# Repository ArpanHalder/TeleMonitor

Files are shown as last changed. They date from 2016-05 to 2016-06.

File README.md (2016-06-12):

# TeleMonitor
This Open Hardware initiative is focused mostly on industrial application. In fact, this started with designing a low-cost Telemonitoring system for Mining Industry Applications. It is an embedded data transmission setup made up on small Arduino like boards. For long distance communication between device nodes, it uses RS-485

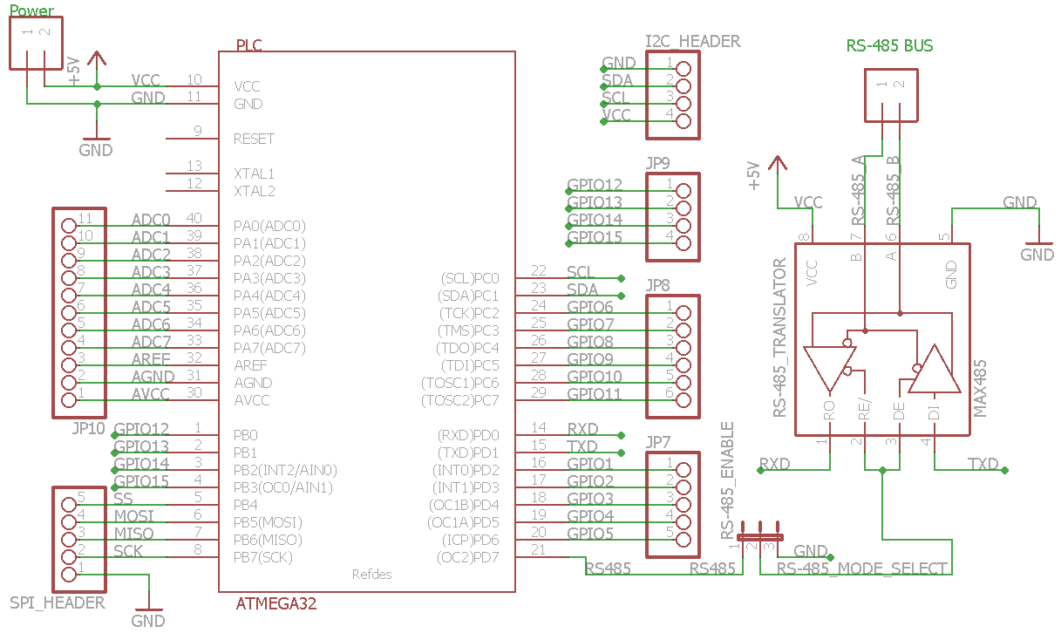
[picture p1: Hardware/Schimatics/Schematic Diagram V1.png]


##Motivation
While working in the laboratory, our team did experiment similar thing using state of the art services. However, not every educational institute has access to premium facilities. This project is initiated to enable us (who have access to premium education) to build some full-scale copyleft open technology that can be used for demonstration of remote monitoring operation in academia as well as in industries.
(After the device, hopefully soon the projects for IDE of this instrument, and Open Source Analytics & Visualization tools for this project shall be published after development of first working prototype.)

##Design Approaches
One of the primary objectives is keeping the hardware cheap, straightforward and reparable. We don't want a design where if one component fails the whole circuit is replaced, which create extra junk on the surface of the earth.

###This Device is motivated by the idea of "Democratisation of Technology & Education."
<https://en.wikipedia.org/wiki/Democratization_of_technology>

<http://www.thehindu.com/news/national/andhra-pradesh/science-should-touch-lives-of-common-people/article8539013.ece>

This is why we wish to keep the design simple and affordable like DIY projects, however, rich with all necessary features. This we can hopefully achieve by the cognitive support of the community. We also suggest restricting use of components in the design that tier III nations cannot afford to import or implement in the industries. 

##Ways to Contribute in this project

Discuss the possible improvement, and feature requirements.

Contact : tech.halder.arpan@gmail.com

[master_diag]: https://github.com/ArpanHalder/TeleMonitor/blob/master/Hardware/Schimatics/Schematic%20Diagram%20V1.png

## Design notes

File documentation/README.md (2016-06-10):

#Images depict

Network Layers in BUS implimentation of telemonitor board :"TeleMonitorProtocol.PNG"

Abstract concept of TeleMonitor Device : "Abstract Concept .png"

Pin mapping in TeleMonitor: "ATmega 40 Pin layout.PNG"

//TODO : Update explaind revison of bare  minimum code skeliton.

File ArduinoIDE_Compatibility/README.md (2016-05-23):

#How to add TeleMonitor Universal IoT Platform on Arduino1.0.x device list.

copy and add contents of boards.txt to existing boards.txt which is in your \<arduino IDE directory\> / hardware/boards.txt

Next copy the folder TeleMonitorATmega16-32 in your \<arduino IDE directory\>/hardware/variants/

then restart the IDE. (in case you're using STINO with sublime-text you only need to refresh.) 

**Please Note:** Here the compatibility files shall only help to program the MCU used in TeleMonitor Device with Arduino as ISP mode.

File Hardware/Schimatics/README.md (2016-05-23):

#Hardware Schematics for Telemonitoring nodes



## How to Read/Open

The files are made with eagle cad. 

There are image files naming  *.PNG  

Currently Schematics is drawn in a way which can easily be implimented with one sided perforated board. (to avoid PCB printing cost for early developers.) 

**Please Note:** the top layer on PCB (the red streaks) need not to be solder bridged, rather a thin wire may be used which shall be soldered on bottom side.

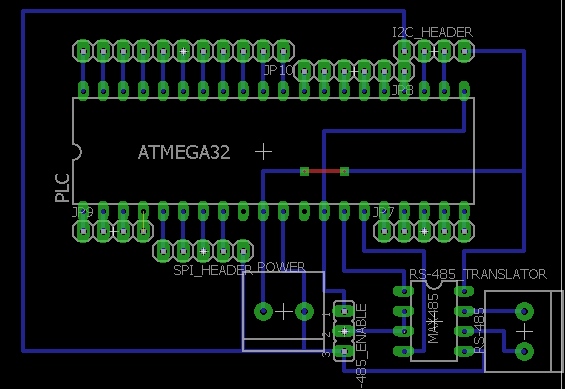
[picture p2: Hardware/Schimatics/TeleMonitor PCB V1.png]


### Current Job
~~Looking forward to make a vias less PCB that can be printed and fabricated manually.~~

~~On Veroboard~~

Add more necessary components and rearrangement for improvements. 

[master_diag]: https://github.com/ArpanHalder/TeleMonitor/blob/master/Hardware/Schimatics/Schematic%20Diagram%20V1.png

[master_pcb]: https://github.com/ArpanHalder/TeleMonitor/blob/master/Hardware/Schimatics/TeleMonitor%20PCB%20V1.png

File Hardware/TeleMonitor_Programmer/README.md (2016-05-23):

# This is Programmer for TeleMonitor MCUs
Preferably this can also be done in breadboard. With Arduino IDE via Arduino as ISP or any other AVR HEX uploader.
## Please note: The top layer (marked as red) needn't to be printed, they are preferably connected manually by means of insulated wires.

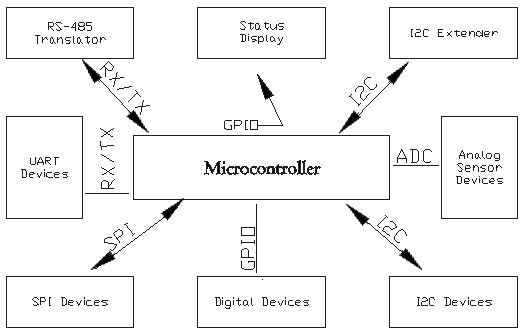
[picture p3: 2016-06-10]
documentation/Abstract Concept .png

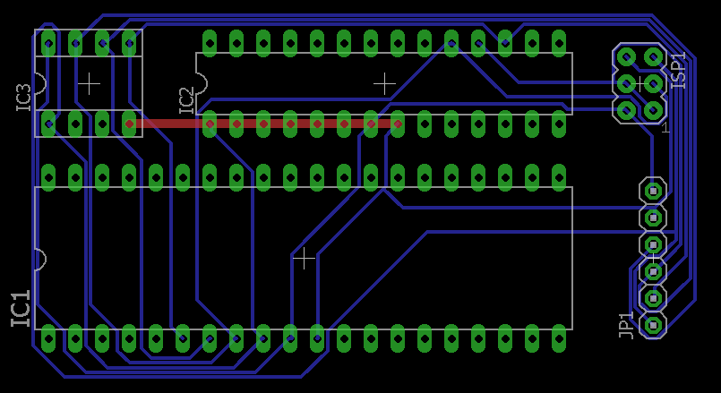
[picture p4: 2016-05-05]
Hardware/TeleMonitor_Programmer/TeleMonitor Programmer PCB V0.3.png

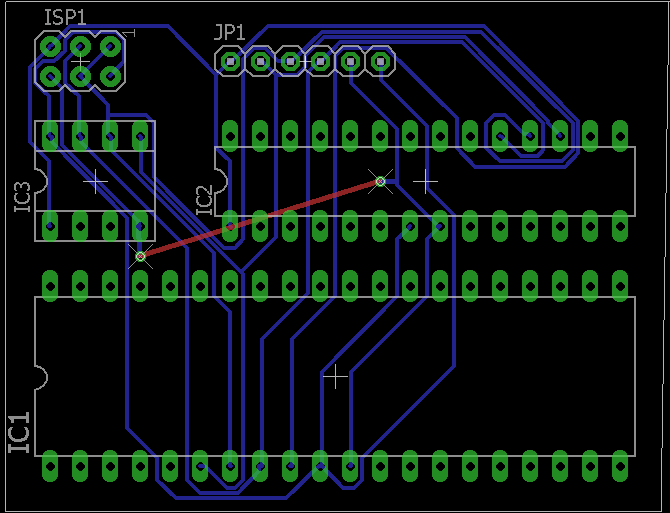
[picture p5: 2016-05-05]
Hardware/TeleMonitor_Programmer/TeleMonitor Programmer PCB V0.2.png

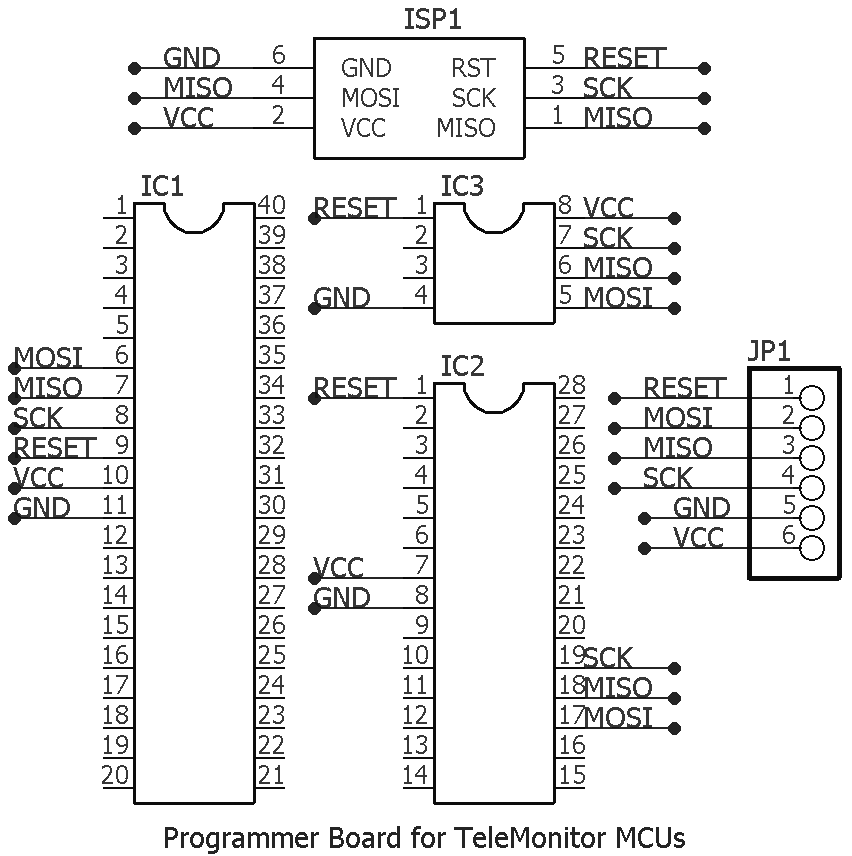
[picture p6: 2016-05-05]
Hardware/TeleMonitor_Programmer/TeleMonitor Programmer Diagram Grayscale.png

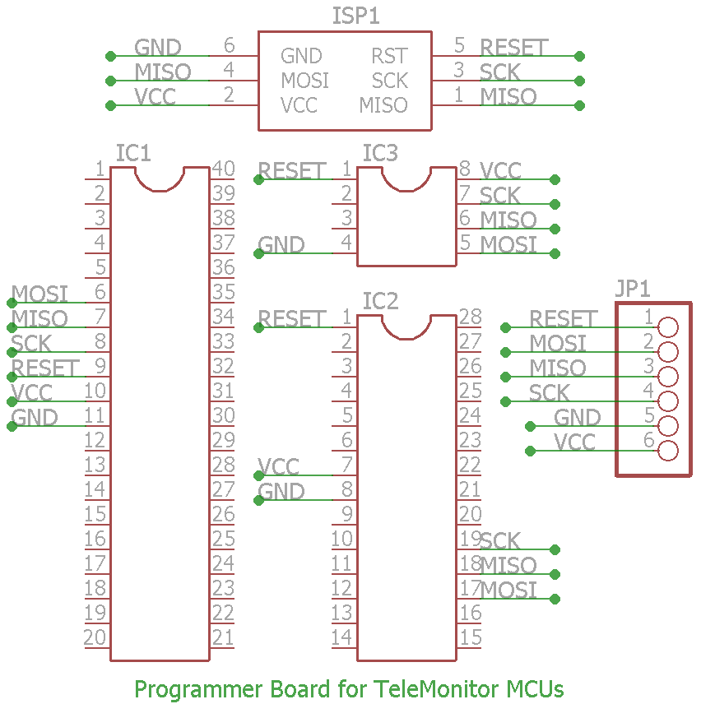
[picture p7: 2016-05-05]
documentation/TeleMonitor Programmer Diagram.png

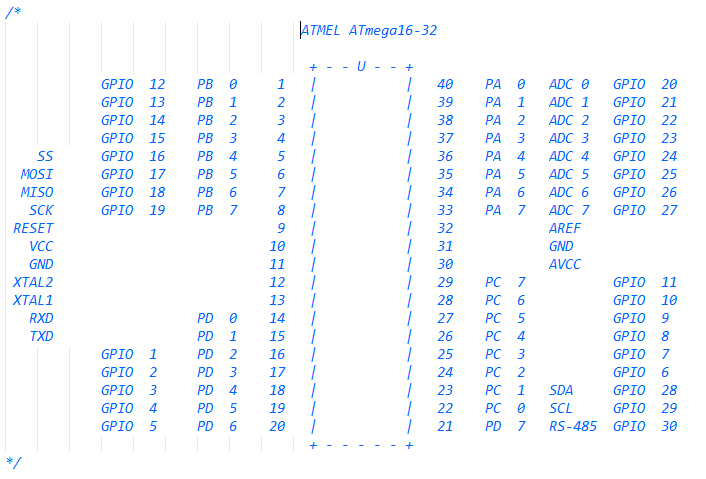
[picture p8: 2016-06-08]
documentation/ATmega 40 Pin layout.PNG

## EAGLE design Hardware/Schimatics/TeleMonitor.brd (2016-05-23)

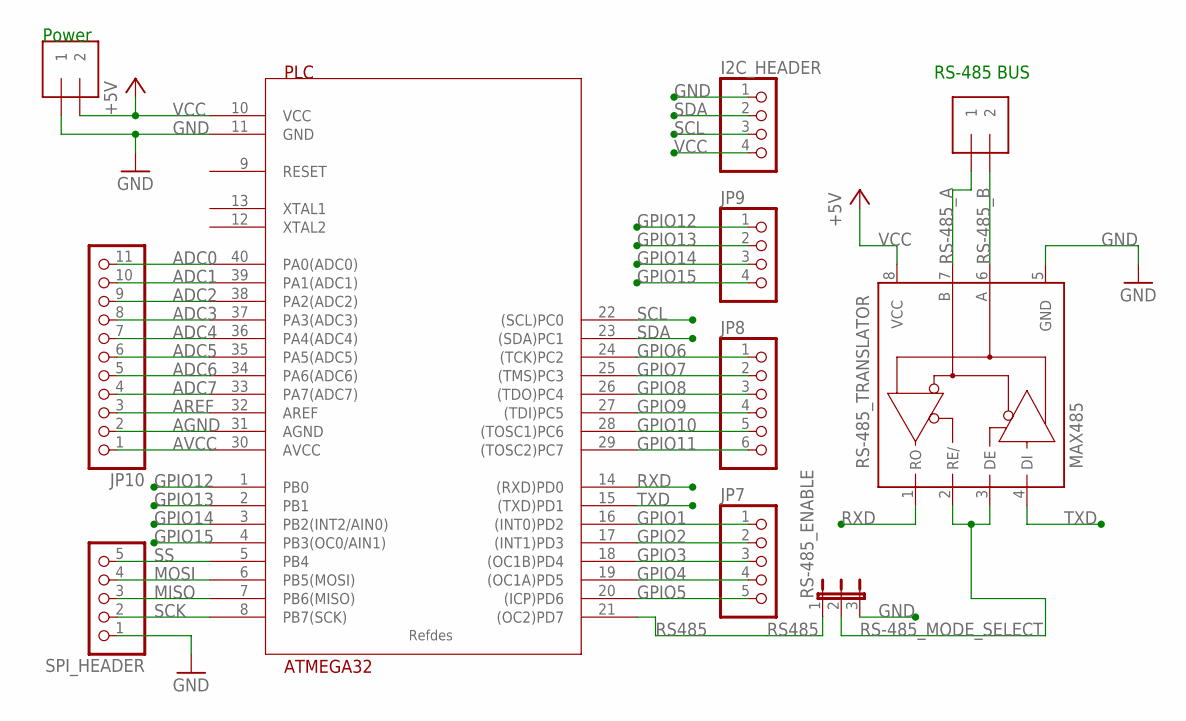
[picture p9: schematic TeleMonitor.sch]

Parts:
I2C_HEADER: PINHD-1X4; 1X04
JP7: PINHD-1X5; 1X05
JP8: PINHD-1X6; 1X06
JP9: PINHD-1X4; 1X04
JP10: PINHD-1X11; 1X11
PLC: ATMEGA32; DIL40
POWER: 5MM_TERMINAL_BLOCK-3.5MM; 1X2-3.5MM
RS-485: 5MM_TERMINAL_BLOCK-3.5MM; 1X2-3.5MM
RS-485_ENABLE: JP2E; JP2
RS-485_TRANSLATOR: MAX485; DIL08
SPI_HEADER: PINHD-1X5; 1X05

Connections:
ADC0: JP10.11, PLC.40 (PA0(ADC0))
ADC1: JP10.10, PLC.39 (PA1(ADC1))
ADC2: JP10.9, PLC.38 (PA2(ADC2))
ADC3: JP10.8, PLC.37 (PA3(ADC3))
ADC4: JP10.7, PLC.36 (PA4(ADC4))
ADC5: JP10.6, PLC.35 (PA5(ADC5))
ADC6: JP10.5, PLC.34 (PA6(ADC6))
ADC7: JP10.4, PLC.33 (PA7(ADC7))
AGND: JP10.2, PLC.31 (AGND)
AREF: JP10.3, PLC.32 (AREF)
AVCC: JP10.1, PLC.30 (AVCC)
GND: I2C_HEADER.1, PLC.11 (GND), POWER.1, RS-485_ENABLE.3, RS-485_TRANSLATOR.5 (GND), SPI_HEADER.1
GPIO1: JP7.1, PLC.16 ((INT0)PD2)
GPIO2: JP7.2, PLC.17 ((INT1)PD3)
GPIO3: JP7.3, PLC.18 ((OC1B)PD4)
GPIO4: JP7.4, PLC.19 ((OC1A)PD5)
GPIO5: JP7.5, PLC.20 ((ICP)PD6)
GPIO6: JP8.1, PLC.24 ((TCK)PC2)
GPIO7: JP8.2, PLC.25 ((TMS)PC3)
GPIO8: JP8.3, PLC.26 ((TDO)PC4)
GPIO9: JP8.4, PLC.27 ((TDI)PC5)
GPIO10: JP8.5, PLC.28 ((TOSC1)PC6)
GPIO11: JP8.6, PLC.29 ((TOSC2)PC7)
GPIO12: JP9.1, PLC.1 (PB0)
GPIO13: JP9.2, PLC.2 (PB1)
GPIO14: JP9.3, PLC.3 (PB2(INT2/AIN0))
GPIO15: JP9.4, PLC.4 (PB3(OC0/AIN1))
MISO: PLC.7 (PB6(MISO)), SPI_HEADER.3
MOSI: PLC.6 (PB5(MOSI)), SPI_HEADER.4
RS485: PLC.21 ((OC2)PD7), RS-485_ENABLE.1
RS-485_A: RS-485.1, RS-485_TRANSLATOR.7 (B)
RS-485_B: RS-485.2, RS-485_TRANSLATOR.6 (A)
RS-485_MODE_SELECT: RS-485_ENABLE.2, RS-485_TRANSLATOR.2 (RE/), RS-485_TRANSLATOR.3 (DE)
RXD: PLC.14 ((RXD)PD0), RS-485_TRANSLATOR.1 (RO)
SCK: PLC.8 (PB7(SCK)), SPI_HEADER.2
SCL: I2C_HEADER.3, PLC.22 ((SCL)PC0)
SDA: I2C_HEADER.2, PLC.23 ((SDA)PC1)
SS: PLC.5 (PB4), SPI_HEADER.5
TXD: PLC.15 ((TXD)PD1), RS-485_TRANSLATOR.4 (DI)
VCC: I2C_HEADER.4, PLC.10 (VCC), POWER.2, RS-485_TRANSLATOR.8 (VCC)

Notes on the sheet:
Power
RS-485 BUS

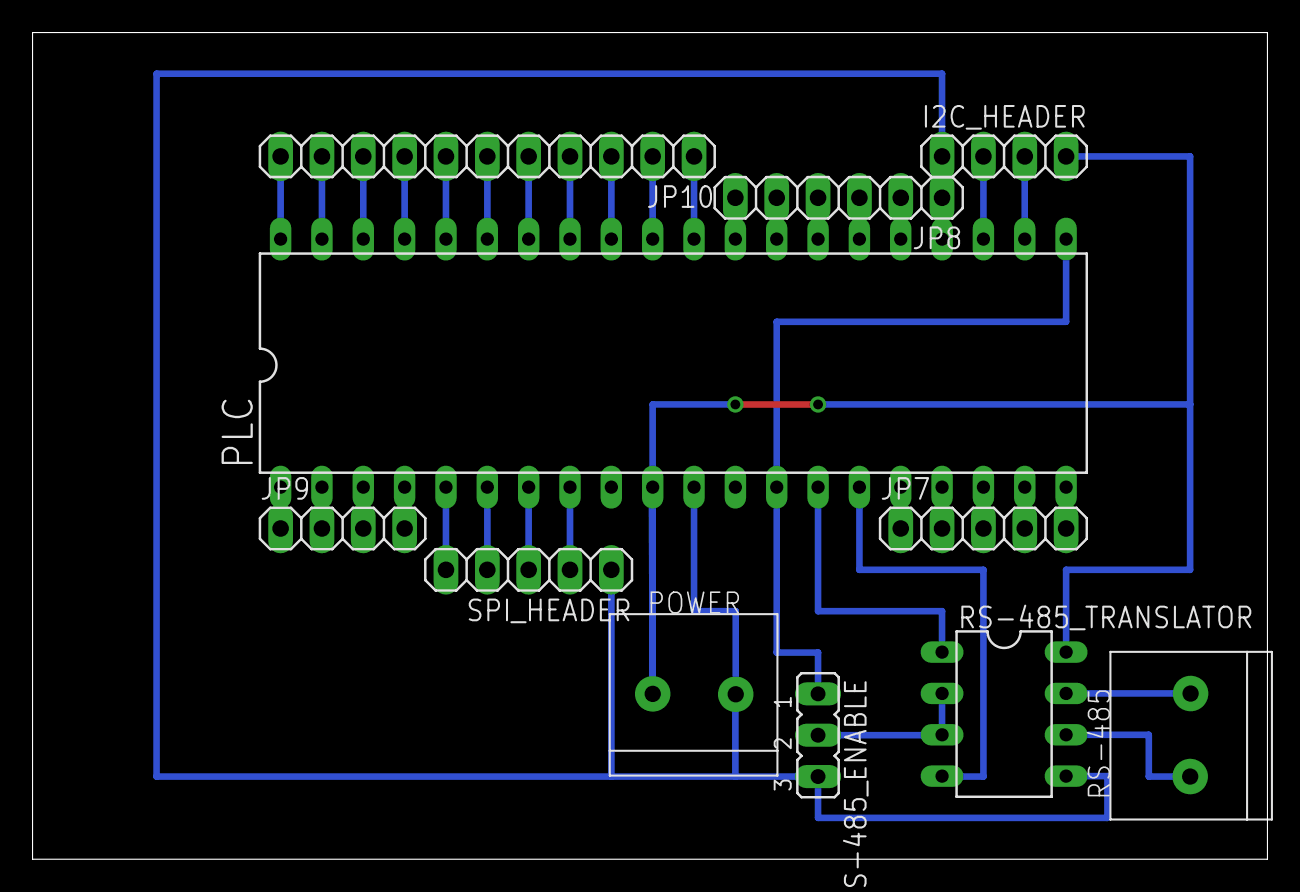
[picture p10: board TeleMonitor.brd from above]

Board: 2 copper layers, 75.9 x 50.8 mm, 11 parts (0 on the bottom side), 40 nets.

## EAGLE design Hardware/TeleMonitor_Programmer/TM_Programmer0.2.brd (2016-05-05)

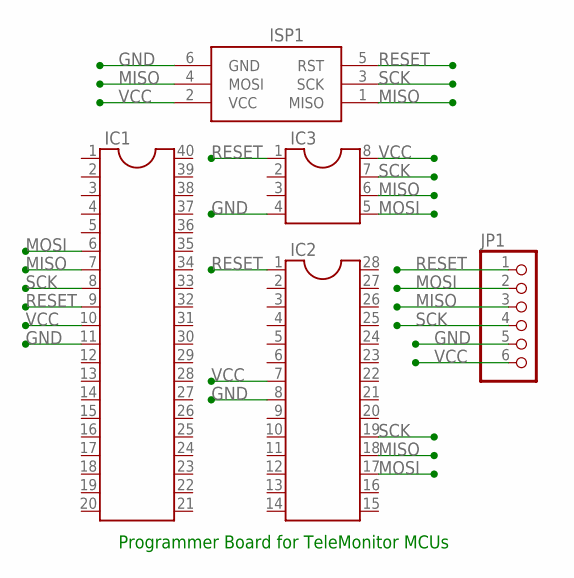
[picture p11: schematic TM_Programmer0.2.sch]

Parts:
IC1: DIL40
IC2: DIL28-3
IC3: DIL8S; SOCKET-08
ISP1: AVRISP-6; AVRISP
JP1: PINHD-1X6; 1X06

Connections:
GND: IC1.11, IC2.8, IC3.4, ISP1.6 (GND), JP1.5
MISO: IC1.7, IC2.18, IC3.6, ISP1.1 (MISO), ISP1.4 (MOSI), JP1.3
MOSI: IC1.6, IC2.17, IC3.5, JP1.2
RESET: IC1.9, IC2.1, IC3.1, ISP1.5 (RST), JP1.1
SCK: IC1.8, IC2.19, IC3.7, ISP1.3 (SCK), JP1.4
VCC: IC1.10, IC2.7, IC3.8, ISP1.2 (VCC), JP1.6

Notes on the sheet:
Programmer Board for TeleMonitor MCUs

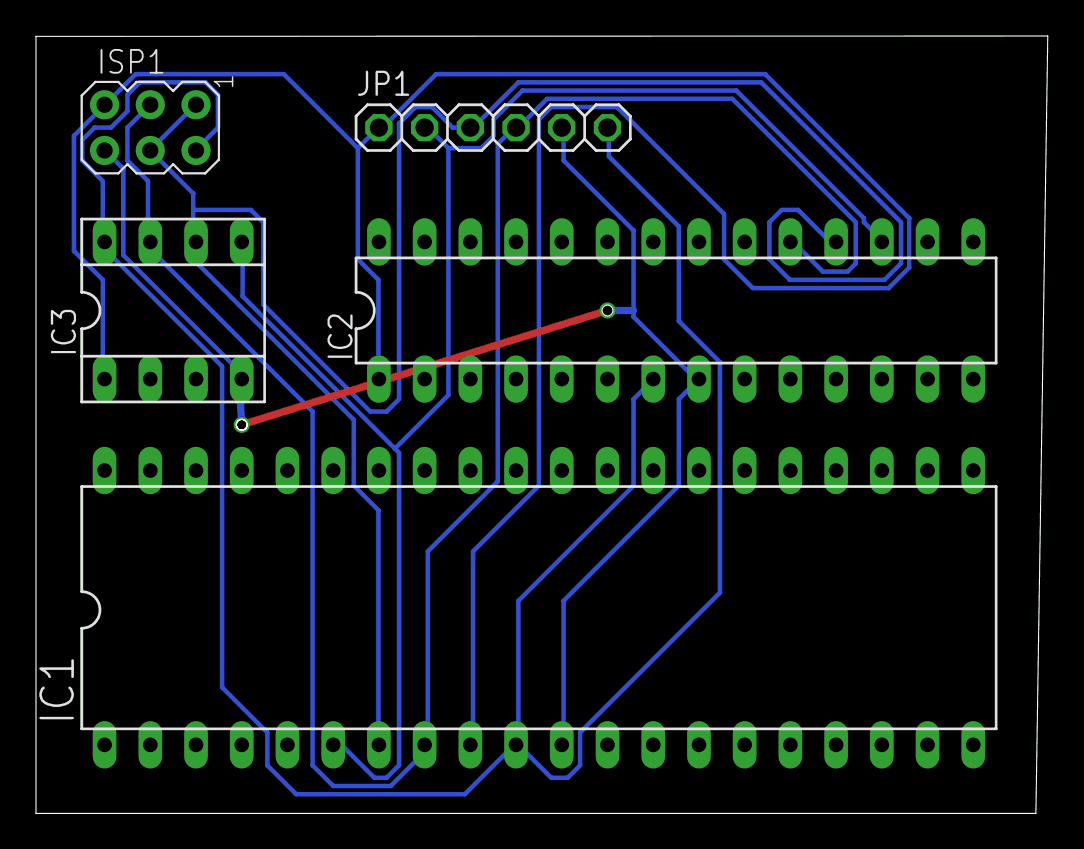
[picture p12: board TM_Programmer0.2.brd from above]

Board: 2 copper layers, 56.2 x 43.2 mm, 5 parts (0 on the bottom side), 6 nets.

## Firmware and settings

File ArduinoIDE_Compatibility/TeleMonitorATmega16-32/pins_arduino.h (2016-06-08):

/*
    Author:		Arpah Halder, Department of Mining Engineering, IIT Kharagpur
	Email:		tech.halder.arpan@gmail.com
	Date:		21-05-2016
	Project:	TeleMonitor
 	Version:	v1.0
	
	Inspired by Eric Conner's ATmega32 for Arduino IDE project
*/

#ifndef Pins_Arduino_h
#define Pins_Arduino_h

#include <avr/pgmspace.h>

#define NOT_ON_TIMER 0
#define TIMER0A 1
#define TIMER0B 2
#define TIMER1A 3
#define TIMER1B 4
#define TIMER2  5

#undef TCCR2A

#define NOT_A_PORT 0
#define NOT_ON_TIMER 0

/*			
		                             ATMEL ATmega16-32			
					
                                      + - - U - - +                                  
            GPIO  12    PB  0     1   |           |   40    PA  0   ADC 0   GPIO  20
            GPIO  13    PB  1     2   |           |   39    PA  1   ADC 1   GPIO  21
            GPIO  14    PB  2     3   |           |   38    PA  2   ADC 2   GPIO  22
            GPIO  15    PB  3     4   |           |   37    PA  3   ADC 3   GPIO  23
    SS      GPIO  16    PB  4     5   |           |   36    PA  4   ADC 4   GPIO  24
  MOSI      GPIO  17    PB  5     6   |           |   35    PA  5   ADC 5   GPIO  25
  MISO      GPIO  18    PB  6     7   |           |   34    PA  6   ADC 6   GPIO  26
   SCK      GPIO  19    PB  7     8   |           |   33    PA  7   ADC 7   GPIO  27
 RESET                            9   |           |   32            AREF             
   VCC                           10   |           |   31            GND              
   GND                           11   |           |   30            AVCC             
 XTAL2                           12   |           |   29    PC  7           GPIO  11
 XTAL1                           13   |           |   28    PC  6           GPIO  10
   RXD                  PD  0    14   |           |   27    PC  5           GPIO  9
   TXD                  PD  1    15   |           |   26    PC  4           GPIO  8
            GPIO  1     PD  2    16   |           |   25    PC  3           GPIO  7
            GPIO  2     PD  3    17   |           |   24    PC  2           GPIO  6
            GPIO  3     PD  4    18   |           |   23    PC  1   SDA     GPIO  28
            GPIO  4     PD  5    19   |           |   22    PC  0   SCL     GPIO  29
            GPIO  5     PD  6    20   |           |   21    PD  7   RS-485  GPIO  30
                                      + - - - - - +                        
*/			


const static uint8_t SDA = 28;
const static uint8_t SCL = 29;

const static uint8_t SS   = 16;
const static uint8_t MOSI = 17;
const static uint8_t MISO = 18;
const static uint8_t SCK  = 19;

static const uint8_t A0 = 0;
static const uint8_t A1 = 1;
static const uint8_t A2 = 2;
static const uint8_t A3 = 3;
static const uint8_t A4 = 4;
static const uint8_t A5 = 5;
static const uint8_t A6 = 6;
static const uint8_t A7 = 7;

#define NUM_DIGITAL_PINS            32
#define NUM_ANALOG_INPUTS           8
#define analogInputToDigitalPin(p)  ((p < 8) ? (p) + 24 : -1)//TODO : MAPPING
#define digitalPinHasPWM(p)         ((p) == 4 || (p) == 5 || (p) == 7) //TODO: MPPING

#ifdef ARDUINO_MAIN

const uint16_t PROGMEM port_to_mode_PGM[] = {
	NOT_A_PORT,
	(uint16_t) &DDRA,
	(uint16_t) &DDRB,
	(uint16_t) &DDRC,
	(uint16_t) &DDRD,
	NOT_A_PORT,
	NOT_A_PORT,
};

const uint16_t PROGMEM port_to_output_PGM[] = {
	NOT_A_PORT,
	(uint16_t) &PORTA,
	(uint16_t) &PORTB,
	(uint16_t) &PORTC,
	(uint16_t) &PORTD,
	NOT_A_PORT,
	NOT_A_PORT,
};

const uint16_t PROGMEM port_to_input_PGM[] = {
	NOT_A_PORT,
	(uint16_t) &PINA,
	(uint16_t) &PINB,
	(uint16_t) &PINC,
	(uint16_t) &PIND,
	NOT_A_PORT,
	NOT_A_PORT,
};

const uint8_t PROGMEM digital_pin_to_port_PGM[30] = {
PD	,	 	 //	 	PD2	 	>>>	GPIO		1
PD	,	 	 //	 	PD3	 	>>>	GPIO		2
PD	,	 	 //	 	PD4	 	>>>	GPIO		3
PD	,	 	 //	 	PD5	 	>>>	GPIO		4
PD	,	 	 //	 	PD6	 	>>>	GPIO		5
PC	,	 	 //	 	PC2	 	>>>	GPIO		6
PC	,	 	 //	 	PC3	 	>>>	GPIO		7
PC	,	 	 //	 	PC4	 	>>>	GPIO		8
PC	,	 	 //	 	PC5	 	>>>	GPIO		9
PC	,	 	 //	 	PC6	 	>>>	GPIO	    10
PC	,	 	 //	 	PC7	 	>>>	GPIO		11
PB	,	 	 //	 	PB0	 	>>>	GPIO    	12
PB	,	 	 //	 	PB1	 	>>>	GPIO 		13
PB	,	 	 //	 	PB2	 	>>>	GPIO 		14
PB	,	 	 //	 	PB3	 	>>>	GPIO 		15
PB	,	 	 //	 	PB4	 	>>>	GPIO		16
PB	,	 	 //	 	PB5	 	>>>	GPIO		17
PB	,	 	 //	 	PB6	 	>>>	GPIO		18
PB	,	 	 //	 	PB7	 	>>>	GPIO		19
PA	,	 	 //	 	PA0	 	>>>	GPIO		20
PA	,	 	 //	 	PA1	 	>>>	GPIO		21
PA	,	 	 //	 	PA2	 	>>>	GPIO		22
PA	,	 	 //	 	PA3	 	>>>	GPIO		23
PA	,	 	 //	 	PA4	 	>>>	GPIO		24
PA	,	 	 //	 	PA5	 	>>>	GPIO		25
PA	,	 	 //	 	PA6	 	>>>	GPIO		26
PA	,	 	 //	 	PA7	 	>>>	GPIO		27
PC	,	 	 //	 	PC1	 	>>>	GPIO		28
PC	,	 	 //	 	PC0	 	>>>	GPIO		29
PD	,	 	 //	 	PD7	 	>>>	GPIO		30
};

const uint8_t PROGMEM digital_pin_to_bit_mask_PGM[30] = {	
_BV(2),	 	 //	 	PD	2	 	>>>	GPIO		1
_BV(3),	 	 //	 	PD	3	 	>>>	GPIO		2
_BV(4),	 	 //	 	PD	4	 	>>>	GPIO		3
_BV(5),	 	 //	 	PD	5	 	>>>	GPIO		4
_BV(6),	 	 //	 	PD	6	 	>>>	GPIO		5
_BV(2),	 	 //	 	PC	2	 	>>>	GPIO		6
_BV(3),	 	 //	 	PC	3	 	>>>	GPIO		7
_BV(4),	 	 //	 	PC	4	 	>>>	GPIO		8
_BV(5),	 	 //	 	PC	5	 	>>>	GPIO		9
_BV(6),	 	 //	 	PC	6	 	>>>	GPIO	 10
_BV(7),	 	 //	 	PC	7	 	>>>	GPIO	 11
_BV(0),	 	 //	 	PB	0	 	>>>	GPIO	 12
_BV(1),	 	 //	 	PB	1	 	>>>	GPIO	 13
_BV(2),	 	 //	 	PB	2	 	>>>	GPIO	 14
_BV(3),	 	 //	 	PB	3	 	>>>	GPIO	 15
_BV(4),	 	 //	 	PB	4	 	>>>	GPIO	 16
_BV(5),	 	 //	 	PB	5	 	>>>	GPIO	 17
_BV(6),	 	 //	 	PB	6	 	>>>	GPIO	 18
_BV(7),	 	 //	 	PB	7	 	>>>	GPIO	 19
_BV(0),	 	 //	 	PA	0	 	>>>	GPIO	 20
_BV(1),	 	 //	 	PA	1	 	>>>	GPIO	 21
_BV(2),	 	 //	 	PA	2	 	>>>	GPIO	 22
_BV(3),	 	 //	 	PA	3	 	>>>	GPIO	 23
_BV(4),	 	 //	 	PA	4	 	>>>	GPIO	 24
_BV(5),	 	 //	 	PA	5	 	>>>	GPIO	 25
_BV(6),	 	 //	 	PA	6	 	>>>	GPIO	 26
_BV(7),	 	 //	 	PA	7	 	>>>	GPIO	 27
_BV(1),	 	 //	 	PC	1	 	>>>	GPIO	 28
_BV(0),	 	 //	 	PC	0	 	>>>	GPIO	 29
_BV(7),	 	 //	 	PD	7	 	>>>	GPIO	 30
};
//TODO: TIMER MAPPING
const uint8_t PROGMEM digital_pin_to_timer_PGM[32] = {
	NOT_ON_TIMER,  // PB0 ** D0
	NOT_ON_TIMER,  // PB1 ** D1
	NOT_ON_TIMER,  // PB2 ** D2
	TIMER0A,	   // PB3 ** D3
	NOT_ON_TIMER,  // PB4 ** D4
	NOT_ON_TIMER,  // PB5 ** D5
	NOT_ON_TIMER,  // PB6 ** D6
	NOT_ON_TIMER,  // PB7 ** D7
	NOT_ON_TIMER,  // PD0 ** D8
	NOT_ON_TIMER,  // PD1 ** D9
	NOT_ON_TIMER,  // PD2 ** D10
	NOT_ON_TIMER,  // PD3 ** D11
	TIMER1B,	   // PD4 ** D12
	TIMER1A,	   // PD5 ** D13
	NOT_ON_TIMER,  // PD6 ** D14
	TIMER2,		   // PD7 ** D15
	NOT_ON_TIMER,  // PC0 ** D16
	NOT_ON_TIMER,  // PC1 ** D17
	NOT_ON_TIMER,  // PC2 ** D18
	NOT_ON_TIMER,  // PC3 ** D19
	NOT_ON_TIMER,  // PC4 ** D20
	NOT_ON_TIMER,  // PC5 ** D21
	NOT_ON_TIMER,  // PC6 ** D22
	NOT_ON_TIMER,  // PC7 ** D23
	NOT_ON_TIMER,  // PA7 ** A0 D24
	NOT_ON_TIMER,  // PA6 ** A1 D25
	NOT_ON_TIMER,  // PA5 ** A2 D26
	NOT_ON_TIMER,  // PA4 ** A3 D27
	NOT_ON_TIMER,  // PA3 ** A4 D28
	NOT_ON_TIMER,  // PA2 ** A5 D29
	NOT_ON_TIMER,  // PA1 ** A6 D30
	NOT_ON_TIMER,  // PA0 ** A7 D31
};

#endif
#endif

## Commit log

2016-05-05 Programmer Schematics Uploaded
    [TM_Programmer0.1.brd, TM_Programmer0.1.sch, TM_Programmer0.2.brd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]
2016-05-19 Simplified Schematics:
    That can be implimented with standard 3x2 in veroboards. this is to avoid PCB printing costs.
    [MTP_worp1.brd, MTP_worp1.sch]
2016-05-19 real stuff
    [MTP_worp1.brd, TeleMonitor.brd, TeleMonitor.sch]
2016-05-19 PCB diagrams uploaded
2016-05-21 Updating arduino ide Compatiability contents
2016-05-23 Readme of Schematics
2016-05-23 uploaded Sche edits
    [TeleMonitor.brd, TeleMonitor.sch]
2016-06-08 pic of pin playout atmega 40 pin added
